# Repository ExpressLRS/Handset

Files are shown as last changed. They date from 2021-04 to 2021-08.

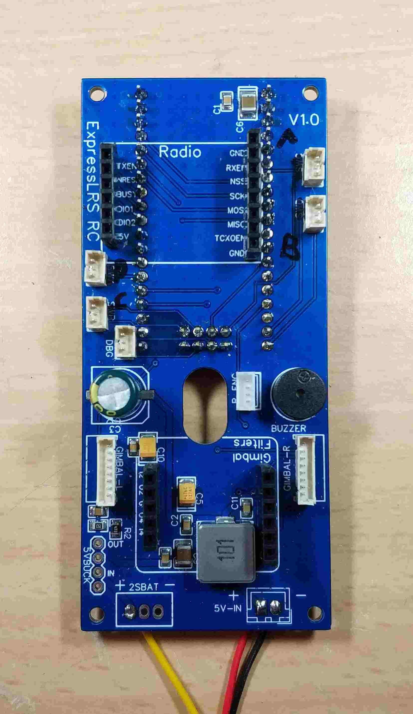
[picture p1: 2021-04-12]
Wiki/images/pcbs/main_component_side.jpg

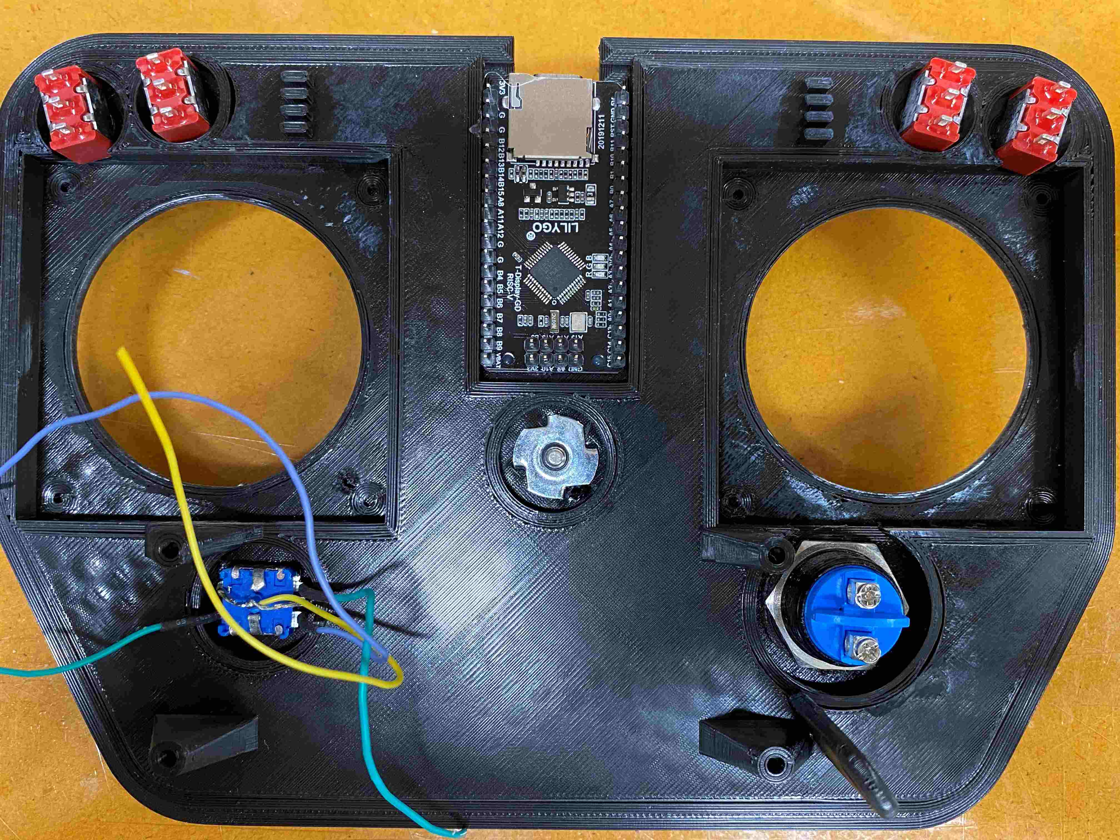
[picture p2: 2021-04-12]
Wiki/Main Board Assembly/20210327_000506065_iOS.jpg

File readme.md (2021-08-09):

The Express LRS Handset project is first and foremost an **experimental test bed** for pushing the envelope with what can be done with the ELRS radio link.  This handset will not replace your "daily driver", nor will it ever support radio protocols other than ELRS.  The Micro Controller Unit (MCU) does not run OpenTX.  The user interface is very rudimentary - simple text menus that are selected with a rotary encoder.  The firmware for this handset will never achieve "Release Candidate", let alone "Stable" status or be assigned a version number.  The software will be a continuous work in progress.

You will have to order and print parts, assemble, and solder this handset by hand as well as know how to build the firmware from source code and upload to the MCU.  

There will be pain.  There will be gnashing of teeth.  At this point is where we give you your first and final warning as passed down by ancient sailors:

***********************************************************
**Beyond this line there be Dragons . . . .**
***********************************************************

OK, now that we've set some expectations for this project we'll list some of the cool features of this handset and explain why you would want to go thru all of the effort to build instead of just purchasing a commercial handset.

1. Fly at the fastest and most consistent packet rate available.  Currently this is 500Hz, but this handset is capable of much faster.  Since the MCU doesn't have to deal with OpenTX, all of its CPU cycles are used to provide the most consistent ELRS signal to the receiver and thus your flight controller.  This is the main goal of this project, to increase the performance and stability of the ELRS radio link.  With this handset, you'll be right on the bleeding edge with the devs.
2. Uses FrSky M10 Hall Effect gimbals.  If you want the best radio signal, you start with the best data.
3. Hardware Filtering of gimbal data.  Select a level of hardware filtering by swapping out custom daughterboards to fine tune your feel.
4. Swappable RF deck.  RF deck is on a replaceable daughterboard so you can swap from 2.4GHz to 900MHz bands. (900 MHz modules currently not developed)  Can also swap to a lower powered RF module to save battery life if you don't need the higher power settings.
5. 1S2P 18650 LiPo battery.  Entire handset sips power from 2 LiPos in parallel.  Fly an entire weekend without charging.
6. Wireless Qi charging.  Build a charging cradle that will wirelessly charge your handset when you're not flying.
7. Internal Moxon antenna.  Transmit antenna is mounted internally for aesthetics, but can be mounted externally simply by drilling a hole.
8. Simplified operation.  Quad fliers rarely use 99% of the mixing functions of OpenTX since all of that is done in the Flight Controller.
9. Parts should be less than $100 U.S.
10. Did I mention wireless Qi charging?

At this time the best source of information on this project is our OneDrive folder:

https://1drv.ms/u/s!Ap0n6SxbLP9mspxu-dxmtthcFGTxvA?e=23NiK6

If you've read this far...



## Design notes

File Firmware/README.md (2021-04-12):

# Express_CX
Firmware for an experimental handset based on ExpressLRS

You're welcome to look around, but the project is still very much a work in progress and isn't particularly consumable yet. It's purpose is to test the limits of current RC technology and is likely only of interest to a very small subset of pilots.

This project builds on the awesome ExpressLRS high performance RC link https://github.com/AlessandroAU/ExpressLRS

The idea is to try and provide the highest quality RC data to the flight controller, building on the low latency, low jitter capabilities of ExpressLRS. The primary target is quadcopters running BetaFlight - this is not intended to be a general purpose RC controller.

The gimbal data is filtered before being sampled at high (currently 128kHz per channel) frequency and then run through the 1AUD filter designed by Chris Thompson https://github.com/ctzsnooze/1AUD-filter. This allows customisable filter settngs to be applied for different use cases. Latency is reduced through increased packet rate, currently up to 1kHz.

In future I hope to experiment with calculating the first and second order derivatives for each channel and sending those over the link along with the absolute stick positions.

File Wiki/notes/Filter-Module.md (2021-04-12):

filter top view

The filter module filters and buffers the signals from the gimbals before they are sampled by the ADC.

The project is on EasyEDA at https://easyeda.com/jbk1/expresscontroller

The circuit is from https://www.electronics-tutorials.ws/filter/second-order-filters.html

The cutoff frequency to use depends on both personal preference and how noisy the gimbals are. I'm currently using a cutoff of 339Hz which seems to work well, and plan to experiment with some higher frequency versions. The main purpose of having the filter on a module is to make it easy to test different cutoff frequencies.

339Hz can be achieved using 10k resistors and 47nF capacitors (or 15k with 33nF is similar at 322Hz). The footprints are for 0805 sized parts. For other cutoff frequencies there is a table of suggested values in the EasyEDA project description.

The pcb includes pads for changing Q using a resistor divider network in the feedback loop. I'm not currently using this, so the divider resistors on the back of the pcb can be left unpopulated. The ones on the front are still needed to complete the feedback circuit, but the value is not critical. I used 10k which would be a reasonable value if we wanted to modify Q later by adding the resistors on the back.

There are footprints for power supply decoupling capacitors on the back of the PCB, two 1210 and two 0805. The power rail is 5V so I'd recommend a 10V minimum rating on these capacitors. The larger ones can be anything in the 10 to 100 uF range, the smaller ones in the range 10 to 100 nF, ideally a mix of different values. The footprints don't have the polarity marked, so if using tantalum take extra care to get them the right way around! (but ceramics are cheaper and work fine here).

There is an assembly "cheat sheet" to help with where each component goes during assembly

build cheat sheet

Rear view of the filter
underside of filter

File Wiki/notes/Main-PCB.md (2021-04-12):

With all the interesting stuff on modules, the main PCB is mostly just filtering and plugs. The V1.0 PCB pictured has several mistakes on the silk screen - those will get fixed in future revisions.

Main pcb component side

Main pcb mcu side

The MCU used is a TTGO GD32V Risc-V board (http://www.lilygo.cn/prod_view.aspx?TypeId=50033&Id=1251). It comes with a good quality LCD and the GD32V processor has good ADC performance for sampling the gimbals at high frequency.

TODO - more info and build instructions

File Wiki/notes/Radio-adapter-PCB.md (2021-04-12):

Radio adapter top view

The radio module is mounted on an adapter pcb to make it easy to swap different versions. Different modules can be used via different adapters, but at the moment the E28 modules are recommended. They are available in 12, 20 and 27 dBm versions and any of these can be used with the same adapter.

The adapter is very straightforward to build, it has a simple 3v3 reg and filter capacitors on the back, and just the E28 on the front.

Don't forget to reposition the 0 ohm resistor on the E28 to use the UFL!

Radio adapter bottom view

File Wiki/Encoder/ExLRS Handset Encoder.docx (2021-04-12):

The encoder is the main input device for the handset. It is a 5-pin component. The side with 2 pins is the momentary switch, and the 3-pins are the encoder. The center pin on the encoder side is ground.

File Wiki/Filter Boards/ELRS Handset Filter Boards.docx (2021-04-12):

ELRS Handset Filter Boards

The ELRS handset uses a daughter board for hardware filtering of the gimbal signals. This is accomplished by routing the gimbal signals through a capacitor / resistor network before sending the signal to the MCU. There are many combinations of capacitor and resistor values that will result in various filtering solutions. Listed below are the 3 combinations we use to start.

Filtering Value | Capacitor | Resistor
322 Hz | 33nF | 15KΩ
530 Hz | 33nF | 9.1KΩ
946 Hz | 33nF | 5.1KΩ

Each filtering board uses 8 capacitors (C1-C8) and 12 resistors (All R’s on U1 side of board)

The filtering board must fit underneath the battery shield with some clearance to ensure there are no inadvertent shorts. When soldering the round pins, make sure the longer pins are the ones soldered into the board so the shorter pins will mate with the sockets in the main board. Also make sure you clip off the extra pins above the board, so it doesn’t contact the battery shield.

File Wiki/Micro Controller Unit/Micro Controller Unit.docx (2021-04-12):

Micro Controller Unit

The Micro Controller Unit (MCU) is the “brains” of the handset. It is installed in the front cover so that the LCD monitor faces out.

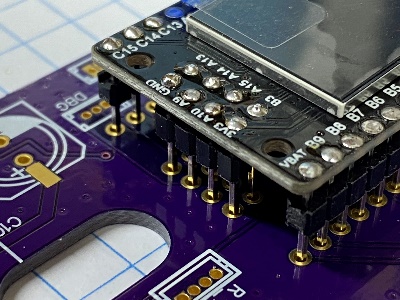
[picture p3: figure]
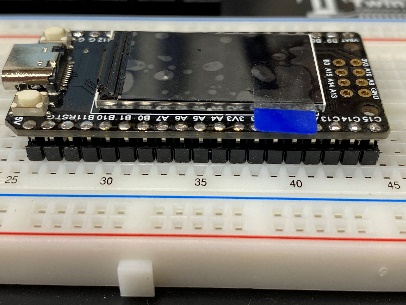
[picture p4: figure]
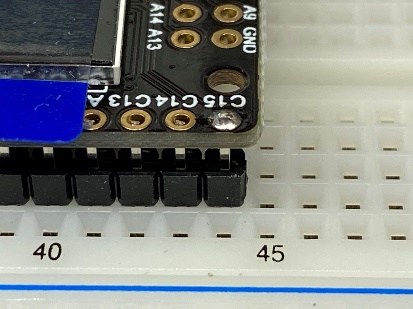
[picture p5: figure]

The MCU’s PCB need to sit as close as possible to the indentation in the case so that the LCD is readable after assembly. To accomplish this, you need to solder the header pins with as little sticking out the top as possible. The easiest way that we found was to utilize a solderless breadboard to hold the header pins until you get the MCU soldered in place.

Once the side header pins are soldered in place, use the Main PCB to locate and hold the 2 x 4 header pins in place for final soldering.

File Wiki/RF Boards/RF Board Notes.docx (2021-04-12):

RF Board Assembly Tips

When soldering the E28 board, smear flux paste onto the pads.

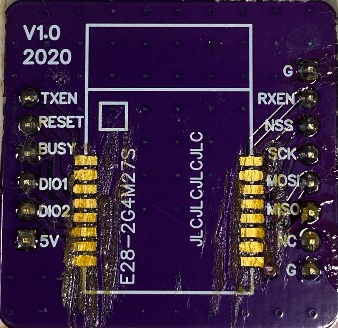
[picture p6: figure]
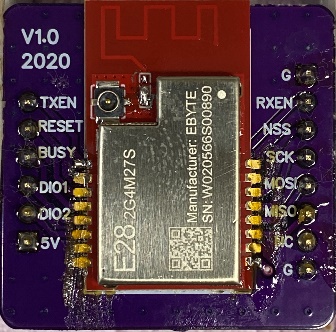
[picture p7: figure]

Place the E28 module on the board. The flux will help hold the module in place. Put a spot of solder paste on two opposite corners and tack the module in place.

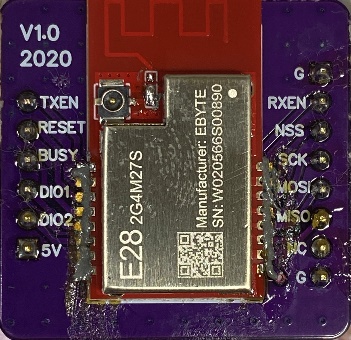
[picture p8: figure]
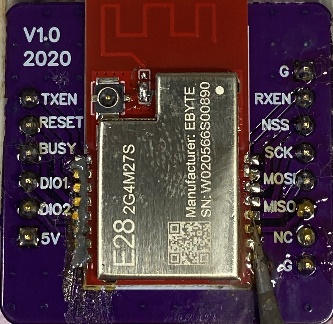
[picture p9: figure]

Put a bead of solder paste along the pads.

Drag solder ((42) HowTo: Drag Soldering Demo - YouTube (https://www.youtube.com/watch?v=wUyetZ5RtPs)) the module in place.

Visually inspect your work to ensure that there are no shorts between pads and that you have good, shiny connections at each point.

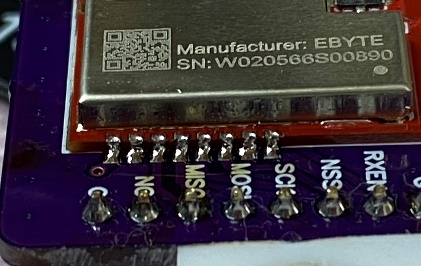
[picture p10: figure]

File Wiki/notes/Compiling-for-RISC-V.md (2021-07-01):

The current version of the handset uses the TTGO T-Display-GD32 RISC-V development board. Unfortunately since this is a relatively new architecture there are some rough edges in the support for it. This page documents the known issues and work-arounds.

1) Conflict with C++ bool in header file

Problem:

```
/home/testuser/.platformio/packages/framework-gd32vf103-sdk/GD32VF103_standard_peripheral/gd32vf103.h:179:41: error: redeclaration of C++ built-in type 'bool' [-fpermissive]
  179 | typedef enum {FALSE = 0, TRUE = !FALSE} bool;
      |                                         ^~~~
```

Cause:

The header file from the gd32 sdk isn't fully C++ compatible yet

Fix:

Comment out line 179 in .platformio/packages/framework-gd32vf103-sdk/GD32VF103_standard_peripheral/gd32vf103.h

```
// typedef enum {FALSE = 0, TRUE = !FALSE} bool;
```

see: https://github.com/riscv-mcu/GD32VF103_Firmware_Library/issues/1

2) Build fails with missing dfu-suffix tool

(Looks like this may have been fixed in recent platformio versions)

Problem:

```
Adding dfu suffix to firmware.bin
sh: 1: bin/dfu-suffix: not found
```

Cause:

dfu tools don't get automatically installed by platformio.

Fix:

Download dfu-utils from https://bintray.com/platformio/tool-packages (use search for tool-dfu to find the right package for your operating system). Extract the archive and copy it to (for linux)

$HOME/.platformio/packages/tool-dfuutil

see https://community.platformio.org/t/dfu-suffix-not-found-for-longan-nano-build/16710/4

3) dfu-util: Cannot open DFU device 28e9:0189

On Linux, indicates a need to add a rule to udev. Either create a new file in /etc/udev/rules.d or add to an existing one if you already have stuff for other dfu (e.g. betaflight FC controllers)

ACTION=="add", SUBSYSTEM=="usb", ATTRS{idVendor}=="28e9", ATTRS{idProduct}=="0189", MODE="0664", GROUP="whichever group you want to use for dfu access"
  
I just use my main userid group for access rather than going to the trouble of adding a special one for dfu.

You may need to run
```
udevadm control --reload-rules
udevadm trigger
```
as root after updating the rules for them to take effect.

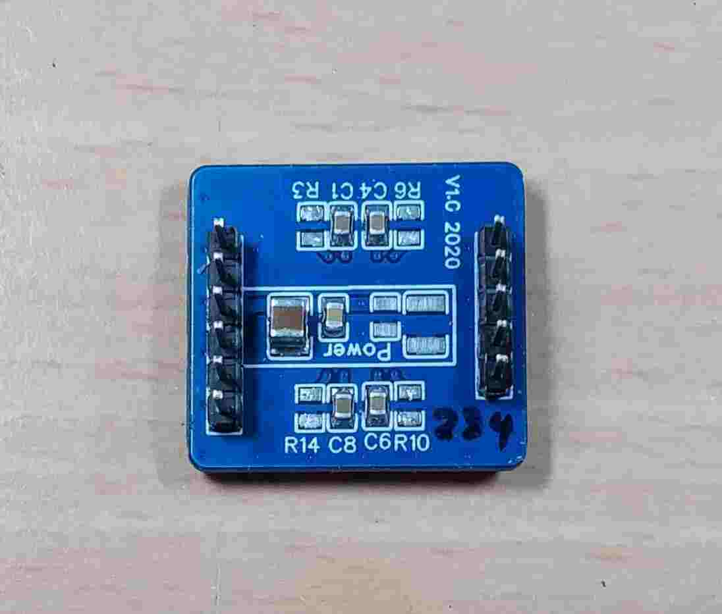
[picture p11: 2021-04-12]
Wiki/images/pcbs/filter_bottom.jpg

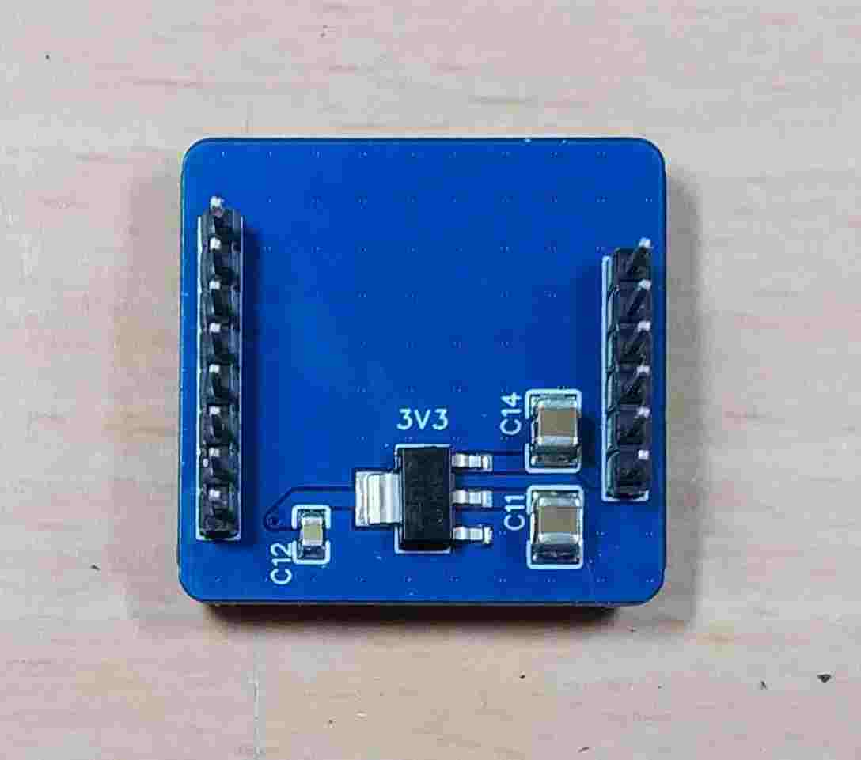
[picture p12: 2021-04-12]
Wiki/images/pcbs/rc_adapter_bottom.jpg

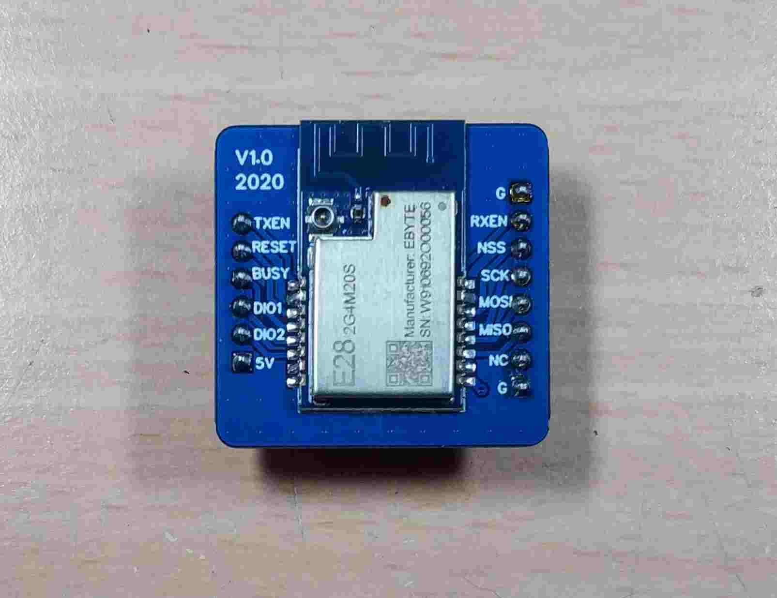
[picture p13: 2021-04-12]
Wiki/images/pcbs/rc_adapter_top.jpg

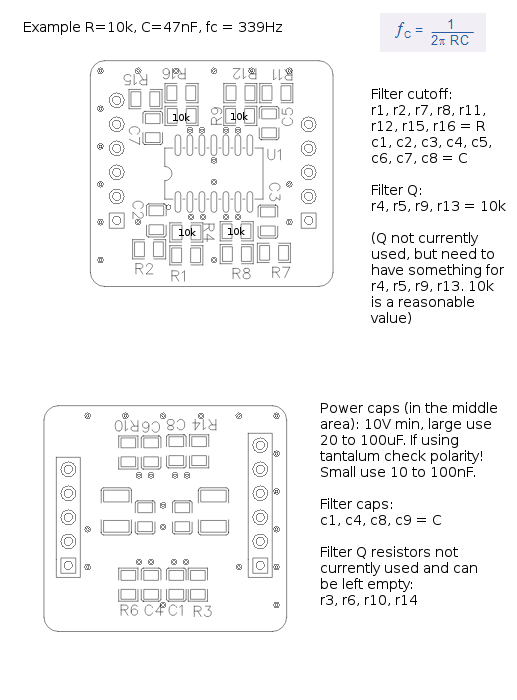
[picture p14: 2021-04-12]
Wiki/images/filter_cheat_sheet.png

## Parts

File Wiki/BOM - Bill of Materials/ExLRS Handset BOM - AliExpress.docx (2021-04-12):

# Stuff you’ll need to order from AliExpress

# (Quantities and specifics are in RED)

# E28-2G4M27S SX1280 Wireless module 2.4G 27dBm SPI Wireless ranging positioning LoRa Wireless Transceiver Long range 8000m

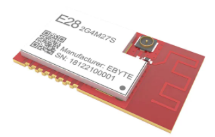
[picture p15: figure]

- E28 2G4M27S SX1280 Wireless module 2.4G 27dBm SPI Wireless ranging positioning LoRa Wireless Transceiver Long range 8000m|Fixed Wireless Terminals| - AliExpress (https://www.aliexpress.com/item/33004335921.html?spm=a2g0s.9042311.0.0.17854c4dX7L4KH)

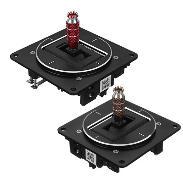
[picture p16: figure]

FrSky M10 Gimbals.

- Frsky m10 high sensitivity hall sensor gimbal for horus x10 x10s rc drone transmitter Sale - Banggood.com (https://usa.banggood.com/FrSky-M10-High-Sensitivity-Hall-Sensor-Gimbal-for-Horus-X10-X10S-RC-Drone-Transmitter-p-1277967.html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)
- FrSky M10 Gimbal For Horus X10 & X10s (horusrc.com) (https://www.horusrc.com/eng/frsky-m10-gimbal-for-horus-x10-x10s.html)

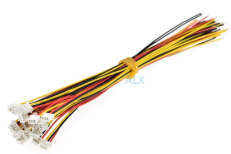
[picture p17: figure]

# 20PCS 150MM mini micro JST 1.25 3pin female plug connector with wire 1.25MM 3pin 3p cable (Order 3 and 4 pin connectors)

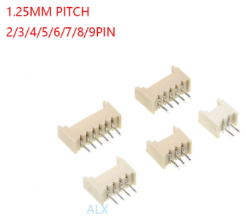
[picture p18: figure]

- 20PCS 150MM mini micro JST 1.25 3pin female plug connector with wire 1.25MM 3pin 3p cable|Connectors| - AliExpress (https://www.aliexpress.com/item/32886112821.html?spm=a2g0s.9042311.0.0.17854c4dX7L4KH)

# 20pcs MICRO JST connector 1.25MM PITCH MALE pin header 3P/4P/8P Straight needle FOR PCB BOARD 1.25 (Order 3,4, and 8P connectors)

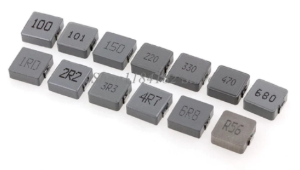
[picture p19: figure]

- 20pcs MICRO JST connector 1.25MM PITCH MALE pin header 2P/3P/4P/5P/6P/7P/8P/9P/10P/11P/12P Straight needle FOR PCB BOARD 1.25|Connectors| - AliExpress (https://www.aliexpress.com/item/32887462907.html?spm=a2g0s.9042311.0.0.17854c4dX7L4KH)

# Integrally Molded 10*10*4 Power Inductor 1040 100UH (Order 100UH Inductors)

- Integrally Molded 10*10*4 Power Inductor 1040 0.56UH 1UH 2.2UH 3.3UH 4.7UH 6.8UH 10UH 100UH 115UH 22UH 33UH 47UH 68UH 10X10X4|Inductors| - AliExpress (https://www.aliexpress.com/item/4000623206812.html?spm=a2g0s.9042311.0.0.17854c4dX7L4KH)

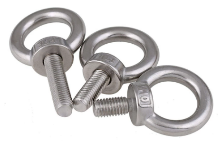
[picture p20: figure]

# M4 Lifting Eye Bolts 304 stainless steel Lifting Ring Screws Eye Bolt (Order M4 Eye Bolts)

- M3 M4 M5 M6 M8 M10 M12 Lifting Eye Bolts 304 stainless steel Lifting Ring Screws Eye Bolt|Bolts| - AliExpress (https://www.aliexpress.com/item/33010957846.html?spm=a2g0s.9042311.0.0.27424c4dr6YM29)

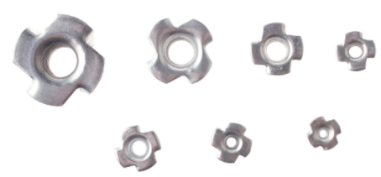
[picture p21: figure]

# 5/10/20/50PCS M3 M4 M5 M6 M8 M10 M12 Zinc Plated Four Claws Nut Speaker T-nut Blind Pronged Insert Tee Nut Furniture Hardware (Order 5 pieces M4 T-Nut)

- 5/10/20/50PCS M3 M4 M5 M6 M8 M10 M12 Zinc Plated Four Claws Nut Speaker T nut Blind Pronged Insert Tee Nut Furniture Hardware|Nuts| - AliExpress (https://www.aliexpress.com/item/33041388035.html)

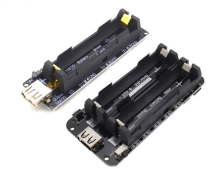
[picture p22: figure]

# ESP32 ESP32S For Wemos For Raspberry Pi 18650 Battery Charge Shield Board V3 Micro USB Port Type-A USB 0.5A (Order the 2-cell shield, no charger)

- ESP32 ESP32S For Wemos For Raspberry Pi 18650 Battery Charge Shield Board V3 Micro USB Port Type A USB 0.5A|Integrated Circuits| - AliExpress (https://www.aliexpress.com/item/4001282850260.html?spm=a2g0s.9042311.0.0.27424c4dr6YM29)


# 10pcs Plum handle 15mm rotary encoder coding switch / EC11 / digital potentiometer with switch 5 Pin

- 10pcs Plum handle 15mm rotary encoder coding switch / EC11 / digital potentiometer with switch 5 Pin|Potentiometers| - AliExpress (https://www.aliexpress.com/item/32879562482.html?spm=a2g0s.9042311.0.0.27424c4dr6YM29)


# Flysky / Frsky Taranis QX7 X7S X9D Plus Transmitter Parts Tighten Switch Spacer Tool

- Flysky / Frsky Taranis QX7 X7S X9D Plus Transmitter Parts Tighten Switch Spacer Tool|Parts & Accessories| - AliExpress (https://www.aliexpress.com/item/32995614382.html?spm=a2g0s.9042311.0.0.27424c4dr6YM29)


# Switch For RadioLink AT9S Futaba JR Frsky X9D Plus QX7 FlySky Walkera WFLY RadioLink switch parts (Be sure to select your desired switches, washers, and nuts)

- Switch For RadioLink AT9S Futaba JR Frsky X9D Plus QX7 FlySky Walkera WFLY RadioLink switch parts|Parts & Accessories| - AliExpress (https://www.aliexpress.com/item/33017227469.html?spm=a2g0s.9042311.0.0.27424c4dr6YM29)


# U.FL IPX IPEX UFL to RP-SMA SMA Female Male Antenna WiFi Pigtail 1.13 Cable ufl 1.13mm Pick Your Length (Order SMA Female 90, 15cm length)

# - U.FL IPX IPEX UFL to RP SMA SMA Female Male Antenna WiFi Pigtail 1.13 Cable ufl 1.13mm Pick Your Length|Connectors| - AliExpress (https://www.aliexpress.com/item/4000166668788.html?spm=a2g0s.9042311.0.0.27424c4dr6YM29)


# LILYGO® TTGO T-Display-GD32 GD32VF103CBT6 Main Chip ST7789 1.14 Inch IPS 240x135 Resolution Minimalist Development Board


- LILYGO® TTGO T Display GD32 GD32VF103CBT6 Main Chip ST7789 1.14 Inch IPS 240x135 Resolution Minimalist Development Board|Circuits| - AliExpress (https://www.aliexpress.com/item/4000598356310.html?spm=a2g0s.9042311.0.0.27424c4dr6YM29)

# 100PCS LM324DR LM324 SOP-14 3.9MM (Only need 3, but 100 qty. is smallest I could find)

- 100PCS LM324DR LM324 SOP 14 3.9MM|amplifier home|amplifier 3gamplifier bluetooth - AliExpress (https://www.aliexpress.com/item/849324878.html?spm=a2g0s.9042311.0.0.27424c4dr6YM29)


# 1pcs Wireless Charging Board 10W Fast Qi Standard Charging Universal DIY 3-Coils PCB (Order both transmitter and receiver)

- 1pcs Wireless Charging Board 10W Fast Qi Standard Charging Universal DIY 3 Coils PCB|Integrated Circuits| - AliExpress (https://www.aliexpress.com/item/32980118867.html?spm=a2g0s.9042311.0.0.27424c4dsHPZHS)

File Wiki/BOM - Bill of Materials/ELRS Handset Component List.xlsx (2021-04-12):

ELRS PCB Component Callouts
Main PCB
C1, C2,C4, C8, C11 | 1uF
C3, C12 | 470uF | Only need one or the other, there are footprints for an SMD or through hole capacitor in this space
C5, C6, C10 | 100uF | Tantalum Cap. Check polarity when installing.
C7 | 0.1uF
C9 | 22uF
C13 | Not used
C14 | 10uF
R1 | 16K
R2 | 47.5K
Power Inductor | 100uH
Buzzer |  | Needs to be the type that beeps when you feed it power, like used on quads. 5mm between pins
Gimbal-R/L | 8-pin socket
SWA/B/C/D/DBG | 3-pin socket
R ENC | 4-pin socket | Alternative: 3-pin socket using the 3 holes closest to the bottom of board. Top hole is ground.
Filter Board
R1, R2, R4, R5, R7, R8, | 5.1K or 9.1K or 15K | <<-- This value selects the filter board speed 946Hz/530Hz/322Hz
R9, R11, R12, R16, R15, R17 |  | <<-- This value selects the filter board speed 946Hz/530Hz/322Hz
C1, C2, C3, C4, C5, C6, C7, C8 | 33nF
Power Large capacitor | 10 to 100 uF | Only need to populate one large and one small power capacitor position.
Power Small capacitor | 0.01 to 0.1 uF | Only need to populate one large and one small power capacitor position.
R3, R6, R10, R14 | Unpopulated
RF Board
RF Module | E28 Ebyte RF Module | 3 models available with 12, 20 and 27dBm output.
 |  | 12dBm is ok for small indoors, 20dBm is a good tradeoff between range and battery life,
 |  | and 27dBm is your max range option
3V3 | 3.3V Regulator
C11, C14 | 10 to 100 uF
C12 | 0.1 uF

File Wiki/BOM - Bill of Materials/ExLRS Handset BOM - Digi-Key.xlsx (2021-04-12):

Manufacturer Part Number | Manufacturer | Digi-Key Part Number | Customer Reference | Reference Designator | Packaging | Part Status | Quantity | Unit Price | Extended Price | Quantity Available | Mfg Std Lead Time | Description | RoHS Status | Lead Free Status | REACH Status
CL21B105KOFNNNG | Samsung Electro-Mechanics | 1276-6471-1-ND | ExLRS Tx Handset | C1, C2,C4, C8, C11 | Cut Tape (CT) | Active | 5 | 0.1 | $0.50 | 264049 | 28 Weeks | CAP CER 1UF 16V X7R 0805 | ROHS3 Compliant | Lead free | REACH Unaffected
CL21B104KACNNNC | Samsung Electro-Mechanics | 1276-1099-1-ND | ExLRS Tx Handset | C7 | Cut Tape (CT) | Active | 1 | 0.1 | $0.10 | 32023 | 28 Weeks | CAP CER 0.1UF 25V X7R 0805 | ROHS3 Compliant | Lead free | REACH Unaffected
CL21A226MOCLRNC | Samsung Electro-Mechanics | 1276-6780-1-ND | ExLRS Tx Handset | C9 | Cut Tape (CT) | Active | 1 | 0.36 | $0.36 | 902296 | 28 Weeks | CAP CER 22UF 16V X5R 0805 | ROHS3 Compliant | Lead free | REACH Unaffected
RMCF0805FT47K5 | Stackpole Electronics Inc | RMCF0805FT47K5CT-ND | ExLRS Tx Handset | R2 | Cut Tape (CT) | Active | 1 | 0.1 | $0.10 | 139544 | 21 Weeks | RES 47.5K OHM 1% 1/8W 0805 | ROHS3 Compliant | Lead free | REACH Unaffected
RC0805FR-0716KL | Yageo | 311-16.0KCRCT-ND | ExLRS Tx Handset | R1 | Cut Tape (CT) | Active | 1 | 0.1 | $0.10 | 497289 | 20 Weeks | RES SMD 16K OHM 1% 1/8W 0805 | ROHS3 Compliant | Lead free | REACH Unaffected
16ZLJ470MTA8X11.5 | Rubycon | 1189-1549-1-ND | ExLRS Tx Handset | C3, C12 | Cut Tape (CT) | Active | 2 | 0.53 | $1.06 | 37385 | 20 Weeks | CAP ALUM 470UF 20% 16V RADIAL | ROHS3 Compliant | Lead free | REACH Unaffected
C0805C333K1RECAUTO | KEMET | 399-C0805C333K1RECAUTOCT-ND | ExLRS Tx Handset |  | Cut Tape (CT) | Active | 1 | 0.27 | $0.27 | 4271 | 27 Weeks | CAP CER 0805 33NF 100V X7R 10% | ROHS3 Compliant | Lead free | REACH Unaffected
RC0805FR-075K1L | Yageo | 311-5.10KCRCT-ND | ExLRS Tx Handset |  | Cut Tape (CT) | Active | 1 | 0.1 | $0.10 | 1475887 | 20 Weeks | RES SMD 5.1K OHM 1% 1/8W 0805 | ROHS3 Compliant | Lead free | REACH Unaffected
RC0805FR-0710KL | Yageo | 311-10.0KCRCT-ND | ExLRS Tx Handset |  | Cut Tape (CT) | Active | 1 | 0.1 | $0.10 | 11495312 | 20 Weeks | RES SMD 10K OHM 1% 1/8W 0805 | ROHS3 Compliant | Lead free | REACH Unaffected
RC0805FR-0720KL | Yageo | 311-20.0KCRCT-ND | ExLRS Tx Handset |  | Cut Tape (CT) | Active | 1 | 0.1 | $0.10 | 1049813 | 20 Weeks | RES SMD 20K OHM 1% 1/8W 0805 | ROHS3 Compliant | Lead free | REACH Unaffected
CL32F106ZOHNNNE | Samsung Electro-Mechanics | 1276-2865-1-ND | ExLRS Tx Handset | C11, C14 | Cut Tape (CT) | Active | 1 | 0.32 | $0.32 | 2360 | 28 Weeks | CAP CER 10UF 16V Y5V 1210 | ROHS3 Compliant | Lead free | REACH Unaffected
CL32A226MOJNNNE | Samsung Electro-Mechanics | 1276-1851-1-ND | ExLRS Tx Handset |  | Cut Tape (CT) | Active | 1 | 0.39 | $0.39 | 22823 | 28 Weeks | CAP CER 22UF 16V X5R 1210 | ROHS3 Compliant | Lead free | REACH Unaffected
CL21B104KACNNNC | Samsung Electro-Mechanics | 1276-1099-1-ND | ExLRS Tx Handset | C12 | Cut Tape (CT) | Active | 1 | 0.1 | $0.10 | 32023 | 28 Weeks | CAP CER 0.1UF 25V X7R 0805 | ROHS3 Compliant | Lead free | REACH Unaffected
GRM2195C1H113JA01D | Murata Electronics | 490-8297-1-ND | ExLRS Tx Handset |  | Cut Tape (CT) | Active | 1 | 0.44 | $0.44 | 20 | 23 Weeks | CAP CER 0.011UF 50V C0G/NP0 0805 | ROHS3 Compliant | Lead free | Not Available
293D107X06R3B2TE3 | Vishay Sprague | 718-293D107X06R3B2TE3CT-ND | ExLRS Tx Handset |  | Cut Tape (CT) | Active | 1 | 0.6 | $0.60 | 3029 | 44 Weeks | CAP TANT 100UF 20% 6.3V 1411 | ROHS3 Compliant | Lead free | Not Available
PPTC061LFBN-RC | Sullins Connector Solutions | S7004-ND | ExLRS Tx Handset |  | Tray | Active | 10 | 0.483 | $4.83 | 64319 | 5 Weeks | CONN HDR 6POS 0.1 TIN PCB | ROHS3 Compliant | Lead free | REACH Unaffected
PPTC081LFBN-RC | Sullins Connector Solutions | S7006-ND | ExLRS Tx Handset |  | Tray | Active | 10 | 0.608 | $6.08 | 194620 | 5 Weeks | CONN HDR 8POS 0.1 TIN PCB | ROHS3 Compliant | Lead free | REACH Unaffected
PPTC051LFBN-RC | Sullins Connector Solutions | S6103-ND | ExLRS Tx Handset |  | Tray | Active | 1 | 0.47 | $0.47 | 22819 | 5 Weeks | CONN HDR 5POS 0.1 TIN PCB | ROHS3 Compliant | Lead free | REACH Unaffected
CMI-9605-0580T | CUI Devices | 102-CMI-9605-0580T-ND | ExLRS Tx Handset |  | Box | Active | 10 | 1.11 | $11.10 | 348 | 11 Weeks | BUZZER, 9.6 MM X 5 MM DEEP, M, 5 | ROHS3 Compliant | Lead free | Not Available
CL21B473KBCNNNC | Samsung Electro-Mechanics | 1276-1250-1-ND | ExLRS Tx Handset |  | Cut Tape (CT) | Active | 1 | 0.1 | $0.10 | 3929 | 28 Weeks | CAP CER 0.047UF 50V X7R 0805 | ROHS3 Compliant | Lead free | REACH Unaffected
RC0805FR-079K1L | Yageo | 311-9.10KCRCT-ND | ExLRS Tx Handset |  | Cut Tape (CT) | Active | 1 | 0.1 | $0.10 | 44142 | 20 Weeks | RES SMD 9.1K OHM 1% 1/8W 0805 | ROHS3 Compliant | Lead free | REACH Unaffected
RC0805FR-0715KL | Yageo | 311-15.0KCRCT-ND | ExLRS Tx Handset |  | Cut Tape (CT) | Active | 1 | 0.1 | $0.10 | 554381 | 20 Weeks | RES SMD 15K OHM 1% 1/8W 0805 | ROHS3 Compliant | Lead free | REACH Unaffected
SMC-1-12-1-GT | Adam Tech | 2057-SMC-1-12-1-GT-ND |  |  | Bulk | Active | 1 | 0.78 | $0.78 | 155 | 9 Weeks | MACHINE PIN SOCKET 12P 2.54MM PI | ROHS3 Compliant | Lead free | REACH Unaffected
D01-9922046 | Harwin Inc. | 952-1900-ND |  |  | Tube | Active | 2 | 4.03 | $8.06 | 668 | 8 Weeks | CONN SIL HDR MALE PIN 20POS TIN | ROHS3 Compliant | Lead free | REACH Unaffected

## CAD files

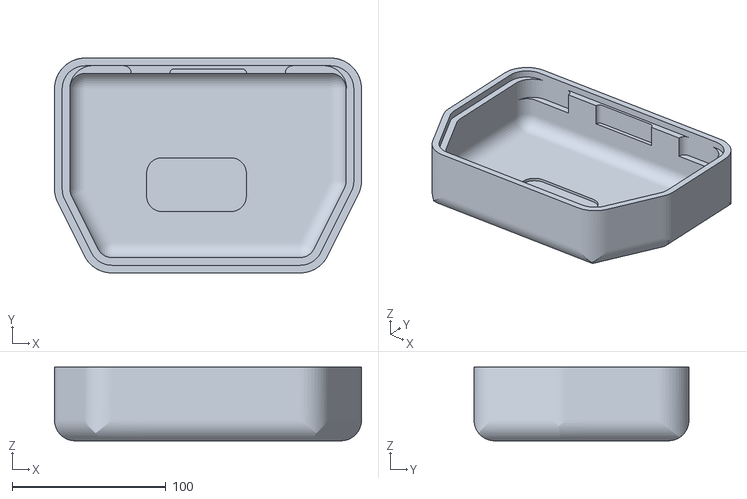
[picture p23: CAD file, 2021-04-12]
ELRS Transmitter Case .STLs/ELRS Handset Bottom.stl
200.0 x 140.0 x 48.0

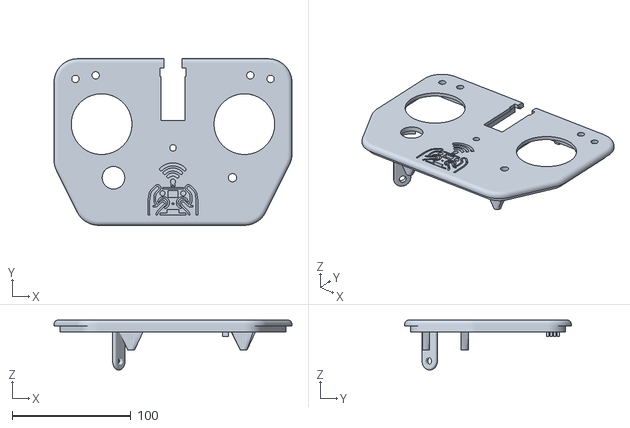
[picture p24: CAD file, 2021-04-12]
ELRS Transmitter Case .STLs/ELRS Handset Top (No Initials).stl
200.0 x 140.0 x 42.0

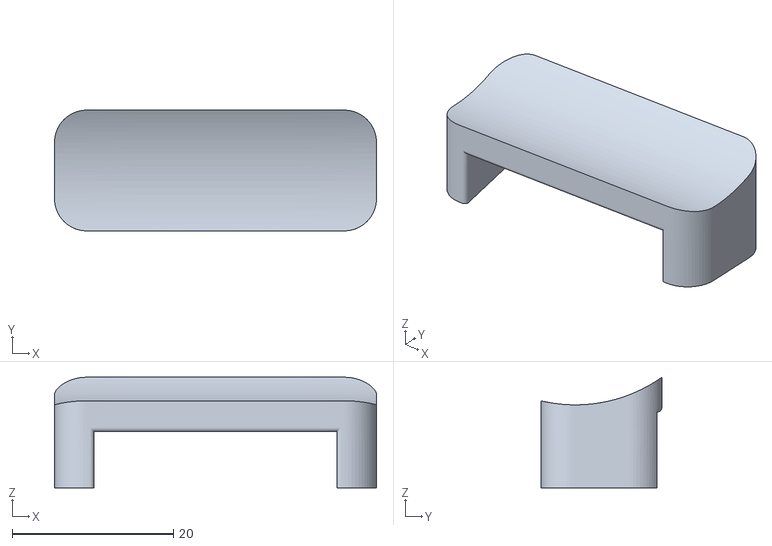
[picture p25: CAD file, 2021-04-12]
ELRS Transmitter Case .STLs/Front Foot (3D Print).stl
40.0 x 15.0 x 13.7

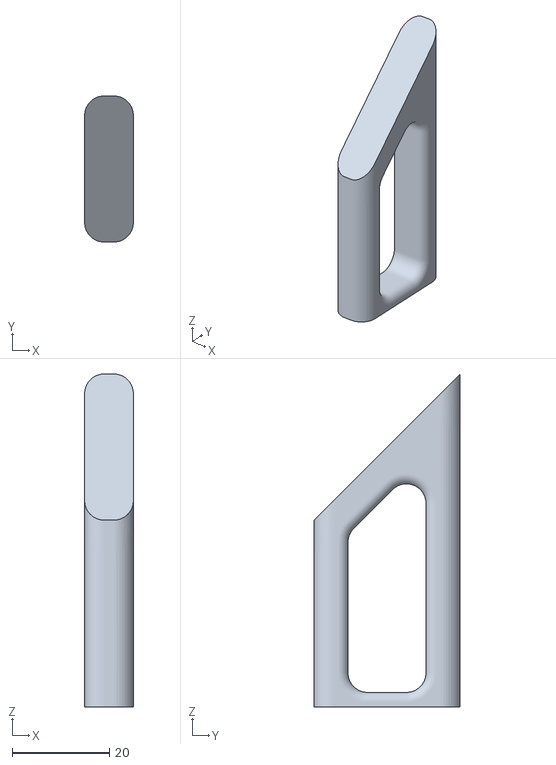
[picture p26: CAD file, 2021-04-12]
ELRS Transmitter Case .STLs/Rear Foot (3D Print).stl
10.0 x 30.0 x 68.4

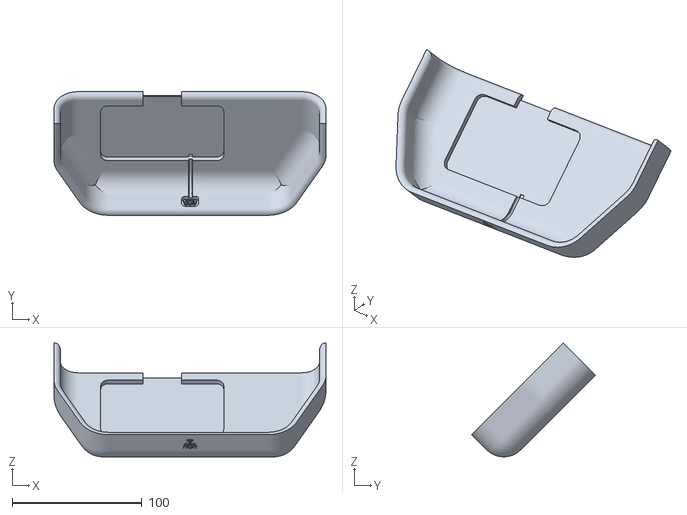
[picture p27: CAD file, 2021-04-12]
ELRS Transmitter Case .STLs/Cradle (3D Print).stl
210.0 x 95.5 x 87.8

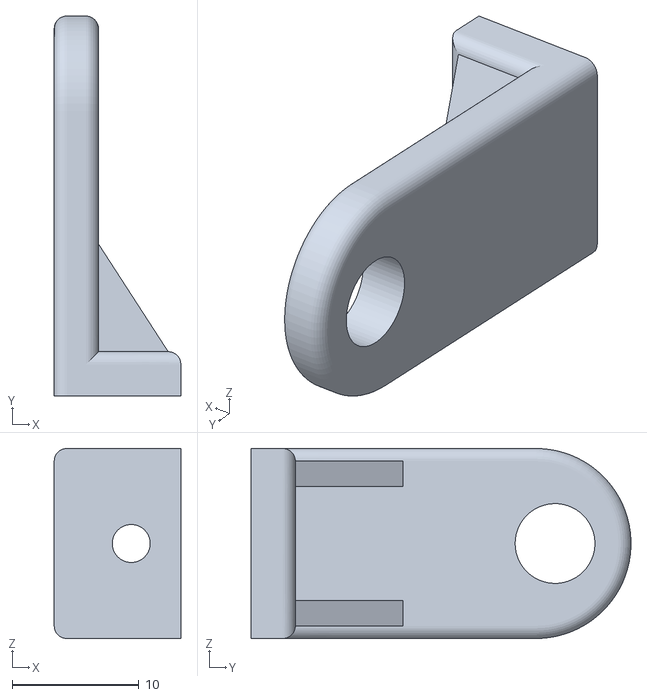
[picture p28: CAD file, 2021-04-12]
ELRS Transmitter Case .STLs/Internal Antenna Mount.stl
10.0 x 30.0 x 15.0

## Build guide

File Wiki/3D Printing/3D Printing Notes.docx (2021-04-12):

3D Printing Instructions

- Use filament with a high temperature tolerance if possible, like ABS. The case will spend time in the hot trunk of your car and some of the components will get warm during use or charging. With that being said, my prototypes were all printed from PLA and they survived.
- Set your slicer “Horizontal Layer” thickness to at least 1 – 1.5mm, especially when printing the front cover. There are several components like the 4mm T-nut and the screws that will need some material to bite into to hold.
- If you need to make a hole for screws, use a hot soldering iron.

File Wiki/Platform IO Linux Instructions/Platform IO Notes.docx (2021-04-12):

Notes for Platform I/O on Linux

To use the UBS-C port on the RISC-V MCU, Platform IO needs to have dfu-util installed.

Index of /releases (sourceforge.net) (http://dfu-util.sourceforge.net/releases/)

Change platformio.ini, comment/uncomment your upload method:

upload_protocol = dfu

; upload_protocol = serial

; upload_port = /dev/ttyUSB1

Linux users have to install udev (https://en.wikipedia.org/wiki/Udev) rules for PlatformIO supported boards/devices. The latest version of rules may be found at https://raw.githubusercontent.com/platformio/platformio-core/master/scripts/99-platformio-udev.rules

Frequently Asked Questions — PlatformIO 5.2.0a4 documentation (https://docs.platformio.org/en/latest/faq.html)

Comment out the following line in file:

-See “Using Platform I/O with RISC-V" in the notes folder.

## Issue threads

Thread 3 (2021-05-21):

How to bind the receiver

norulers, 2021-05-21:
HI，
I made a handset, how to work with my (targets=DIY_2400_RX_ESP8285_SX1280_via_UART) receiver connection ？
Edit  platformio.ini   -D MY_UID=0x17,0x13,0x31,0x19,0x23,0xEB   ?

JBKingdon, 2021-05-21:
Yes, the UID from normal elrs is printed near the start of the build, so copy those values into your handset Ini to match.

JBKingdon, 2021-05-21:
Jump in the elrs discord #handset if you have questions 😃

JBKingdon, 2021-05-21:
The handset firmware has to match a particular release of the Rx firmware. The handset code in the master branch has a define to set the level, currently tested against elrs v1 rc3

norulers, 2021-05-25:
``Verbose mode can be enabled via `-v, --verbose` option
UID bytes: 10,183,12,124,56,3
Installing GitPythonRequirement already satisfied: GitPython in c:\users\norulers\.platformio\penv\lib\site-packages (3.1.17)

JBKingdon, 2021-06-27:
Hey @norulers - sorry I must have missed your last update. Did you get things working?

JBKingdon, 2021-07-28:
Hi @norulers , how are things going? Do we still need this issue or shall I close it now?

norulers, 2021-07-29:
After updating the firmware, it can be used normally.

Closed 2021-07-29.

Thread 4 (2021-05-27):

Switches not working correctly with elrs V1 RC2+

JBKingdon, 2021-05-27:
The switches aren't updating correctly. If aux2 is moved, changes to aux3 and aux4 are ignored until aux2 is moved back to it's original position. Similarly aux3 blocks aux4.

Closed 2021-05-27.

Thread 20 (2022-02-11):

the one drive link isn't working...

JonnyPhenomenon, 2022-02-11:
dead link to onedrive on the handset readme.md

JBKingdon, 2022-02-12:
Ah, that's a shame. FireNWater put that together when he was doing his build.

FireNWater, 2022-02-12:
Ahhh, the link must have timed out. I’ll see if I can send it to James again.

daygp, 2022-04-07:
Seems that the onedrive link on the handset readme.md is down again

JBKingdon, 2022-04-09:
Ah, sorry about that. We'll have to see if we can move the information over to the wiki where it's easier to get at. I should probably also mention that this project is a bit out of date at the moment - I still haven't done the updates for compatibility with elrs v2

Ultraexpert, 2022-10-03:
Will this work with v.3? It would be fun to build this tx?

JBKingdon, 2022-10-03:
> Will this work with v.3? It would be fun to build this tx?

I'm afraid the current software doesn't support elrs V3 or even V2. It would be possible to bring it up to date, but it's a fair bit of work and I can't give any estimate of if/when it will get done.

meistertek, 2024-04-29:
> I'm afraid the current software doesn't support elrs V3 or even V2. It would be possible to bring it up to date, but it's a fair bit of work and I can't give any estimate of if/when it will get done.

What would be involved to update this project to V3 Express LRS. I have some experience designing and fabricating boards using KiCad. I have also fabricated and programmed these boards using small cnc mill. I also have programmed these boards using the processing and MicroPython programming languages. Would these skill sets be enough to update and resurrect the ELRS Handset project?

JBKingdon, 2024-04-29:
Responded in https://github.com/ExpressLRS/Handset/issues/23

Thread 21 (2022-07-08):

hardware filtering

armor66, 2022-07-08:
Just for the record and guess issue should be closed. My hardware filtering board with uPC324G didn't work properly. So I took rail-to-rail MC33204 and there are no troubles with low input.

JBKingdon, 2022-07-25:
Hi, thanks for the update, that's useful to know.

Closed 2022-07-25.

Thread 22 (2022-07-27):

Telemetry support

armor66, 2022-07-27:
Hi, can you please make it clear if it possible to get the rest telemetry data from FC. Why "TLMheader" is always 0x01? I guess that would be 0x14 for link statistics and 0x02, 0x08, 0x21 for gps, battery and flight mode respectively. Is it ELRS version limitation?

JBKingdon, 2022-08-03:
Hi, I haven't used the extended telemetry from the FC so never implemented support in the handset code. There's quite a lot of complexity you'd need to add to do that, but it should be possible to port it across from mainline elrs if you are motivated.

armor66, 2022-08-03:
Ok. I just saw the comment: "if (TLMheader == 1) // they changed the header value for new telem support" (It confused me, who are "they"). Does this have to do with SX1280 files? I'll try, but C++ isn't my thing.

JBKingdon, 2022-08-04:
That's for dealing with the "basic" telemetry that comes from the receiver itself, things like RSSI, SNR and LQ. "They" in this case means the rest of the devs on the main elrs project. They changed the constant for the packets so I had to update the handset code to match for compatibility mode. For the most part I don't run mainline elrs, I have my own fork to experiment with. I added compatibility mode for a friend so that he could use standard elrs on his receivers (since my fork also requires a custom version of betaflight...)

armor66, 2022-08-04:
Ok, could dig in

Closed 2022-08-04.

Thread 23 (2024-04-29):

Resurrect Project

meistertek, 2024-04-29:
@JBKingdon
> I'm afraid the current software doesn't support elrs V3 or even V2. It would be possible to bring it up to date, but it's a fair bit of work and I can't give any estimate of if/when it will get done.

What would be involved to update this project to V3 Express LRS? I have some experience designing and fabricating boards using KiCad. I have also fabricated and programmed these boards using small cnc mill. I also have programmed these boards using the processing and MicroPython programming languages. Would these skill sets be enough to update and resurrect the ELRS Handset project?

JBKingdon, 2024-04-29:
Hi @meistertek
The main work to be done is to add support for the over-the-air format in V3 and then lots of testing. So the primary skill set needed initially is C/C++.

meistertek, 2024-04-30:
Thanks @JBKingdon , I'll work on building a handset and while doing that I'll take a look at the existing C/C++ code. I'll then look at the V3 over-the-air format code to see if I'd be able to figure out how to add it to the existing handset. And then be ready for lots of testing!

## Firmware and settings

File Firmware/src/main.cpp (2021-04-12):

#include <stdio.h>
#include <string.h>
#include "config.h"
#include "utils.h"
#include "SX1280.h"
#include "SX1280_hal.h" //  only needed for MAX_PRE_PA_POWER
#include "FHSS.h"
#include "SimpleStore.h"

// Next:
//    UI improvements
//    Stick calibration
//    Auto power limit when disarmed - or full dynamic power?

//    msp for vtx channel?
   // Info from BF msp.c:
   // uint16_t newFrequency = sbufReadU16(src);
   // if (newFrequency <= VTXCOMMON_MSP_BANDCHAN_CHKVAL) {  // Value is band and channel
   //     const uint8_t newBand = (newFrequency / 8) + 1;
   //     const uint8_t newChannel = (newFrequency % 8) + 1;
//

// Prevents some debug print statements when uncommented
// #define DEBUG_SUPPRESS

// Uncomment to enable some debug output on the LCD
// #define DEBUG_STATUS

// uncomment for setting up the gimbals
#define STICK_CALIBRATION


extern "C" {

#include "gd32vf103.h"
#include "systick.h"

#ifdef LONGAN_NANO
#include "lcd/lcd.h"
#elif defined(T_DISPLAY) || defined(PCB_V1_0)
#include "lcd-tdisplay/lcd.h"
#else
#error "Define the board type before compiling"
#endif

} // extern "C"

// find a better place for these
#define RC_DATA_PACKET  0b00
#define MSP_DATA_PACKET 0b01
#define SYNC_PACKET     0b10
#define TLM_PACKET      0b11

#define CRSF_FRAMETYPE_LINK_STATISTICS 0x14

#define LCD_PWM_MAX     124
#define LCD_PWM_CHARGING  5
#define LCD_PWM_ARMED    20

enum SWITCH_POSITIONS
{
   SWITCH_LOW,
   SWITCH_MID,
   SWITCH_HIGH
};

// params
enum EDITABLE_PARAMS {
   PARAM_NONE,    // must be first
   PARAM_POWER,
   PARAM_RATE,
   PARAM_TLM_INT,
   PARAM_FILTER_MODE,
   PARAM_SYNC_WHEN_ARMED,
   PARAM_N_PARAMS // must be last
};

uint8_t paramToChange = PARAM_NONE;

bool syncWhenArmed = true; // need this on for testing with no switches attached

// current and sent switch values, used for prioritising sequential switch transmission
uint8_t currentSwitches[MAX_SWITCHES] = {SWITCH_LOW};
uint8_t sentSwitches[MAX_SWITCHES] = {SWITCH_LOW};

uint8_t nextSwitchIndex = 0; // for round-robin sequential switches


// Methods that need to be callable from the C interrupt handlers
extern "C" {
   void SendRCdataToRF();
   void HandleTLM();
   void HandleFHSS();
   void ProcessTLMpacket();
}

// debug baud rate
#define BAUDRATE (460800U)

// low battery warning threshold in tenths of a volt
#define LOW_BAT_THRESHOLD (34)

bool batteryLow = false;

unsigned long interval, adcInterval;
unsigned int nSamples=0;
char debugStr[64];
bool debugReady = false;

// static bool led=0;
unsigned long lastButtonTime = 0;
bool buttonMoved = false;
bool doTX = false;

// storage for DMA ouput from ADC
#define DMA_BUFFER_LEN (4)          // maybe double buffer?
uint16_t adc_value[DMA_BUFFER_LEN];

// Storage format for persistent params
struct persistentData_s {
   int8_t txPower;      // signed so that we don't have to add an offset when saving
   uint8_t airmodeIndex;
   uint8_t telemRatio;
   uint8_t sync;
   uint8_t filterMode;
};

typedef persistentData_s persistentData_t;

#define CONFIG_STORE_ID 1


// filters

#include "1AUDfilterInt.h"

struct filterSpec_s {
   uint16_t minCutoff;
   uint16_t maxCutoff;
   float beta;
};

filterSpec_s raceFilter =      {200, 500, 0.01f};
filterSpec_s freestyleFilter = {100, 250, 0.01f};
filterSpec_s cinematicFilter = {10,   50, 0.01f};

enum FILTER_MODE {
   FILTER_RACE,
   FILTER_FREESTYLE,
   FILTER_CINEMATIC,
   FILTER_NUMBER_MODES
};

uint8_t currentFilterMode = FILTER_FREESTYLE;
filterSpec_s currentFilter = freestyleFilter;

// float minCutoff = 150;  // Hz
// float maxCutoff = 500;  // Hz
// float beta = 0.01f;  // did changing to .02 cause the bumps on the stick bounce?

// slewLimit is now steps per second and gets auto converted when sample rate changes
// NB too high a slew limit will overflow the fixed point math in the filter and cause unstable results
float slewLimit = 150000.0f;  // 10000 limits rate on stick bounce test, 20000 doesn't
// float slewLimit = 0;

// This is actually the rate at which the filters are updated which can be (and is)
// different to the rate the ADCs are running at when using oversampling.
float sampleRate = 8000;    // Hz   XXX keep this in step with the ADC setup

float dCutoff = 50.0f;      // Hz

// OneAUDfilter aud_rollF(minCutoff, maxCutoff, beta, sampleRate, dCutoff, slewLimit);
// OneAUDfilter aud_pitchF(minCutoff, maxCutoff, beta, sampleRate, dCutoff, slewLimit);
// OneAUDfilter aud_yawF(minCutoff, maxCutoff, beta, sampleRate, dCutoff, slewLimit);
// OneAUDfilter aud_throttleF(minCutoff, maxCutoff, beta, sampleRate, dCutoff, slewLimit);

// last param is a guess at the initial value
OneAUDfilterInt aud_roll(currentFilter.minCutoff, currentFilter.maxCutoff, int(1.0f/currentFilter.beta), sampleRate, dCutoff, slewLimit, 2000);
OneAUDfilterInt aud_pitch(currentFilter.minCutoff, currentFilter.maxCutoff, int(1.0f/currentFilter.beta), sampleRate, dCutoff, slewLimit, 2000);
OneAUDfilterInt aud_yaw(currentFilter.minCutoff, currentFilter.maxCutoff, int(1.0f/currentFilter.beta), sampleRate, dCutoff, slewLimit, 2000);
OneAUDfilterInt aud_throttle(currentFilter.minCutoff, currentFilter.maxCutoff, int(1.0f/currentFilter.beta), sampleRate, dCutoff, slewLimit, 300);

// power values in prePA dBm (i.e. what the sx1280 is outputting to the PA or antenna if no PA present)
// int radioPower = -18; // low power testing to check crc/fec behaviour using e28-12
int radioPower = -10; // default for e28-27 (50mW)
// int radioPower = -8; // safe for any module
// int radioPower = -2; // dBm. Max for e28-20
// int radioPower = 0; // dBm. Max for e28-27
// int radioPower = 3; // around 100mW on gnice-27
// int radioPower = 12; // dBm. Testing with e28-12
// gnice-27 max is 13


#define RX_CONNECTION_LOST_TIMEOUT 3000 // Time in ms of no TLM response to consider that we have lost connection

bool isRXconnected = false;

volatile uint8_t NonceTX = 0;

uint32_t SyncPacketLastSent = 0;
uint32_t LastTLMpacketRecvMillis = 0;

SX1280Driver radio;

// telemetry values
int8_t rssi;
uint8_t snr, lq;

#include "crc.h"

GENERIC_CRC8 ota_crc(ELRS_CRC_POLY);



// ======== Interrupt Handlers ============

// Handlers have to be in the C namespace
extern "C" {

// callled at the packet interval to trigger sending rf packets
void TIMER2_IRQHandler(void)
{
   static unsigned long tLast = 0;

   if (SET == timer_interrupt_flag_get(TIMER2, TIMER_INT_CH0))
   {
      unsigned long now = micros();

      // clear interrupt bit or mcu will busy hang
      timer_interrupt_flag_clear(TIMER2, TIMER_INT_CH0);
      interval = tLast == 0 ? 0 : now - tLast;
      tLast = now;

      NonceTX++; // New - just increment the nonce on every frame

      #ifdef ELRS_OG_COMPATIBILITY
      HandleFHSS(); // experimental - can we do fhss here?
      #else
      // fhss is in txdone
      #endif

      SendRCdataToRF();
   }
}

/**
 *    This is where we get notification that there is ADC data ready to be processed
 *    with the 1AUD filter.
 */
unsigned long filterUpdateTime = 0; // for debugging the cpu usage of the filters
void DMA0_Channel0_IRQHandler(void)
{
   static unsigned long last = 0;

   if (SET == dma_interrupt_flag_get(DMA0, DMA_CH0, DMA_INT_FLAG_FTF))
   {
      unsigned long now = micros();
      adcInterval = now - last;
      last = now;

      // clear interrupt bit or mcu will busy hang
      dma_interrupt_flag_clear(DMA0, DMA_CH0, DMA_INT_FLAG_FTF);

      #ifndef ADC_A_CH
      #error "need to define the ADC channel mapping"
      #endif

      aud_roll.update(adc_value[ADC_A_CH]);
      aud_pitch.update(adc_value[ADC_E_CH]);
      aud_throttle.update(adc_value[ADC_T_CH]);
      aud_yaw.update(adc_value[ADC_R_CH]);

      nSamples++;
      now = micros();
      filterUpdateTime += (now - last);
   }   
}

// interrupt handler for rotary encoder push button
void EXTI10_15_IRQHandler(void)
{
   if (RESET != exti_interrupt_flag_get(EXTI_13)){
      exti_interrupt_flag_clear(EXTI_13);
      // if(RESET == gpio_input_bit_get(GPIOA, GPIO_PIN_13)) XXX event loop needs to know about both up and down events
      {
         buttonMoved = true;
         lastButtonTime = millis();
      }
   }
}


void HandleFHSS()
{
   #ifdef ELRS_OG_COMPATIBILITY
   uint8_t modresult = (NonceTX+1) % ExpressLRS_currAirRate_Modparams->FHSShopInterval;
   #else
   uint8_t modresult = (NonceTX + 1) % ExpressLRS_currAirRate_Modparams->FHSShopInterval;
   #endif // ELRS_OG_COMPATIBILITY


   if (modresult == 0) // if it time to hop, do so.
   {
      uint32_t f = FHSSgetNextFreq();
      // printf("f %lu\n\r", f);
      radio.SetFrequency(f);
   }
}

void TXdoneISR()
{
   // printf("TXdone!\n\r");

   // TODO do fhss from timer for both cases
   #ifdef ELRS_OG_COMPATIBILITY
   // fhss moved to timer
   #else
   HandleFHSS();
   #endif

   HandleTLM();
}


// use this for rx and tx done isrs on B8 and B9 (connected to radio DIOs)
void EXTI5_9_IRQHandler(void)
{
   if (exti_interrupt_flag_get(EXTI_8) == SET) {
      exti_interrupt_flag_clear(EXTI_8);
      // printf("RXdone!\n\r");

      // radio.ClearIrqStatus(SX1280_IRQ_RADIO_ALL);

      // gpio_bit_reset(LED_GPIO_PORT, LED_PIN);  // rx has finished, so clear the debug pin

      // TODO move to the event loop?
      radio.readRXData();  // get the data from the sx1280 chip
      ProcessTLMpacket();

   } else if (exti_interrupt_flag_get(EXTI_9) == SET) {
      exti_interrupt_flag_clear(EXTI_9);
      // printf("TXdone!\n\r");

      // radio.ClearIrqStatus(SX1280_IRQ_RADIO_ALL);

      TXdoneISR();
   }
}

// something like this for switches - or maybe just poll them
// void EXTI10_15_IRQHandler(void)
// {

// }

} // extern "C"

// ==================================================

/** extract the gpio port value from a composite port/pin value
 * 
 */
uint32_t PORT(uint32_t compositeGPIOid) {
    uint32_t p = compositeGPIOid >> 16;
    switch (p) {
        case PORTA:
            return GPIOA;
        case PORTB:
            return GPIOB;
        case PORTC:
            return GPIOC;
        default:
            printf("XXX bad port id %lu\n\r", p);
            while(true);
    }

    // can't get here, but suppresses compiler warning
    return 0;
}



/** Sound the beeper
 * NB blocking for duration ms! Will need an async beeper function
 * @param duration time in ms to beep for
 * 
 */
void beep(uint32_t duration)
{
   #ifdef GPIO_BUZZER
   gpio_bit_set(PORT(GPIO_BUZZER), PIN(GPIO_BUZZER));
   delay(duration);
   gpio_bit_reset(PORT(GPIO_BUZZER), PIN(GPIO_BUZZER));
   #endif
}


/** Handle sequences of beeps
 * 
 *  Remember when the current/last beep started,
 *    if now is after beep start + duration, stop the beep
 * 
 *    if now is after beep start + interval, start a new beep
 * 
 * @param interval the delay between beeps in ms
 * @param duration the length of each beep in ms
 * @param currentTime approximate current time in ms
 * 
 * @return true if beeping, false if quiet. Is it useful?
 * 
 * duration should be less than interval. duration of 0 disables beeping
 * 
 * Passes the current time as a param as the call to millis() is quite expensive
 * and we already have a recent value in the caller.
 * 
 */
bool handleBeeps(uint16_t interval, uint16_t duration, uint32_t currentTime)
{
   #ifdef GPIO_BUZZER
   // Static variables to track state across calls
   static uint32_t beepStartTime = 0;
   static bool beeperActive = false;

   if (duration == 0) {
      // make sure the beeper is off
      if (beeperActive) {
         gpio_bit_reset(PORT(GPIO_BUZZER), PIN(GPIO_BUZZER));
         beeperActive = false;
      }
      return false;
   }

   // uint32_t now = millis();

   if (currentTime > (beepStartTime + interval)) {
      if (!beeperActive) {
         // start the beeper
         beepStartTime = currentTime;
         gpio_bit_set(PORT(GPIO_BUZZER), PIN(GPIO_BUZZER));
         beeperActive = true;
      }
      return true;
   }

   if (currentTime > (beepStartTime + duration)) {
      if (beeperActive) {
         // stop the beeper
         gpio_bit_reset(PORT(GPIO_BUZZER), PIN(GPIO_BUZZER));
         beeperActive = false;
      }
      return false;
   }
   #endif // GPIO_BUZZER

   return false;
}


/**
 * Test for our view of if the drone is armed. (armed as in enabled/ready to fly!)
 * Requires that the first switch is the arm switch.
 * Conservatively assume that either middle or high position means armed.
 */
bool isArmed()
{
   return currentSwitches[0] != SWITCH_LOW;
}
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
int main(void)
{
   // uint32_t t0, t1=0;
   // unsigned int nSamples = 0;

   setup();

   Lcd_Init();
   LCD_Clear(DARKBLUE);

   #if defined(T_DISPLAY) || defined(PCB_V1_0)
   setRotation(2);
   #endif

   // startup splash
   BACK_COLOR = DARKBLUE;
   const char * msg = "ExpressLRS";
   int l = strlen(msg);
   int x = LCD_H/2 - l*8/2;
   int y = LCD_W/2 - 8;
   LCD_ShowString(x, y, (u8 const *) msg, WHITE);

   // startup beep?
   #ifdef GPIO_BUZZER
   // beep(30);
   #endif

   delay(500);

   // start the battery monitor ADC (it runs in continuous mode)
   // need to do this before calling checkForChargeMode()
   adc_software_trigger_enable(ADC1, ADC_REGULAR_CHANNEL);

   checkForChargeMode();

   runSafetyChecks();

   LCD_Clear(DARKBLUE);
   BACK_COLOR = DARKBLUE;

   printf("in main\n\r");

   FHSSrandomiseFHSSsequence();

   // Try connecting to the radio
   radio.currFreq = GetInitialFreq();
   radio.Begin();

   #ifdef DISARM_POWER
   radio.SetOutputPower(DISARM_POWER);
   #else
   radio.SetOutputPower(radioPower);
   #endif

   uint8_t linkRateIndex = 0;
   SetRFLinkRate(linkRateIndex);

   // enable the timer for the tx interrupt
   timer_enable(TIMER2);

   // check if we have saved settings in the persistent store
   persistentData_t persistentData = {0,};

   uint8_t res = SimpleStore::read(CONFIG_STORE_ID, sizeof(persistentData), &persistentData);
   if (res == SS_OK) {
      printf("found settings in persistent store\n");

      // unpack the settings from the saved data
      radioPower = persistentData.txPower;
      #ifndef DISARM_POWER
      radio.SetOutputPower(radioPower);
      #endif

      linkRateIndex = persistentData.airmodeIndex;
      SetRFLinkRate(linkRateIndex);

      syncWhenArmed = (bool)persistentData.sync;

      currentFilterMode = persistentData.filterMode;
      updateFilterSettings(currentFilterMode);

      ExpressLRS_currAirRate_Modparams->TLMinterval = (expresslrs_tlm_ratio_e)persistentData.telemRatio;

   } else {
      printf("persistent data not found\n\r");
   }

   // === Next section is the event loop ===

   unsigned long lastDebug = 0;
   int lastEncValue = 100;
   uint8_t lastSWA = SWITCH_LOW;
   uint8_t lastSWB = SWITCH_LOW;
   uint8_t lastSWC = SWITCH_LOW;
   uint8_t lastSWD = SWITCH_LOW;
   unsigned long lastSwitchMoved = 0;
   bool switchesHaveMoved = false;
   uint8_t lastParamToChange = PARAM_NONE;
   bool lcdRedrawNeeded = false;
   uint8_t encRange = 0;
   bool displayNormal = true; // when true, current display is for 'normal' mode, when false, display is for edit mode
   unsigned long uiButtonDown = 0; // timer for long press detection
   bool statusIsArmed = false;
   while(true) 
   {
      // If there is debug info send it to the uart
      // if (debugReady) {
      //    printf("%s\n", debugStr);
      //    debugReady = false;
      // }

      unsigned long now = millis();

      // RC switches

      // get the current status of the switches
      uint32_t newSWA = getSwitchState(SWA_HIGH, SWA_LOW);
      uint32_t newSWB = getSwitchState(SWB_HIGH, SWB_LOW);
      uint32_t newSWC = getSwitchState(SWC_HIGH, SWC_LOW);
      uint32_t newSWD = getSwitchState(SWD_HIGH, SWD_LOW);

      // if any switch has moved, update the timestamp
      if (newSWA != lastSWA || newSWB != lastSWB || newSWC != lastSWC || newSWD != lastSWD) {
         lastSwitchMoved = now;
         lastSWA = newSWA;
         lastSWB = newSWB;
         lastSWC = newSWC;
         lastSWD = newSWD;
         switchesHaveMoved = true; // TODO rename as rcSwitchesHaveMoved to distuinguish from UI stuff?
      }

      // if a switch has moved, but not for more than the debounce time, then update the active state
      if (switchesHaveMoved && ((now - lastSwitchMoved) > 2)) {
         currentSwitches[0] = newSWA;
         currentSwitches[1] = newSWB;
         currentSwitches[2] = newSWC;
         currentSwitches[3] = newSWD;

         printf("switches: %lu %lu %lu %lu\n\r", newSWA, newSWB, newSWC, newSWD);

         // clear the flag so we don't spam this code
         switchesHaveMoved = false;

         // cancel edit mode if switches are being moved
         if (paramToChange != PARAM_NONE) {
            lastParamToChange = paramToChange;
            paramToChange = PARAM_NONE;
         }

         // since a switch change might cause a display change, force a quick update
         lcdRedrawNeeded = true;
      }

      // Timeout edit mode if UI hasn't been touched
      // Don't worry about wrap around, it's not worth the effort
      if ((paramToChange != PARAM_NONE) && (now  > (lastButtonTime + 15000))) {
         lastParamToChange = paramToChange;
         paramToChange = PARAM_NONE;
         lcdRedrawNeeded = true;
      }

      // Check for long press on the ui button
      // Don't worry about wrap around
      if (uiButtonDown && (now > (uiButtonDown + 1000))) {
         // long press
         printf("long press detected\n\r");
         uiButtonDown = 0; // clear the timer so we don't spam through this code

         LCD_Clear(DARKBLUE);

         BACK_COLOR = YELLOW;
         const char * msg = "SAVED";
         int l = strlen(msg);
         int x = LCD_H/2 - l*8/2;
         int y = LCD_W/2 - 8;
         LCD_ShowString(x, y, (u8 const *) msg, BLACK);

         // populate the data structure
         persistentData.txPower = radioPower;
         persistentData.airmodeIndex = ExpressLRS_currAirRate_Modparams->index;
         persistentData.sync = syncWhenArmed;
         persistentData.filterMode = currentFilterMode;
         persistentData.telemRatio = ExpressLRS_currAirRate_Modparams->TLMinterval;

         SimpleStore::write(CONFIG_STORE_ID, sizeof(persistentData), &persistentData);

         // give the user time to bask in his success
         delay(500);

         LCD_Clear(DARKBLUE);         
         BACK_COLOR = DARKBLUE;
      }

      // UI button (press down on the rotary enc)
      // TODO add double click, use to exit the settings screen (or maybe change between screens, or action a menu item?)
      if (buttonMoved && ((now - lastButtonTime) > 5)) { // time for the button to stop bouncing
         // check the current button state, pressed is pin low
         if(RESET == gpio_input_bit_get(RE_BUTTON_PORT, RE_BUTTON_PIN))
         {
            // printf("ui button pressed\n\r");

            // save the button down time for long press detection
            uiButtonDown = now;

            if (paramToChange == PARAM_NONE && lastParamToChange != PARAM_NONE) {
               paramToChange = lastParamToChange;
               lastParamToChange = PARAM_NONE; // to make sure we only use this once after a timeout
            } else {
               paramToChange = (paramToChange + 1) % PARAM_N_PARAMS;
               // skip PARAM_NONE as that causes exit from edit mode
               if (paramToChange == PARAM_NONE) paramToChange++;
            }
            lcdRedrawNeeded = true; // update the screen immediately 

            // setup the rotary encoder for the selected param
            // The encoder count changes by 2 for each click, so ranges have a *2 multiplier
            switch (paramToChange) {
               case PARAM_POWER:
                  encRange = ((MAX_PRE_PA_POWER + 18) * 2); // MAX_PRE_PA_POWER is the last usable value, not the number of values, so don't subtract 1
                  lastEncValue = (radioPower + 18) * 2 + 100;
                  // printf("currP %d lastEnc %u\n\r", radio.currPWR, lastEncValue);
                  break;

               case PARAM_RATE:
                  encRange = (RATE_MAX - 1) * 2;
                  lastEncValue = ExpressLRS_currAirRate_Modparams->index * 2 + 100;
                  break;

               case PARAM_TLM_INT:
                  encRange = (TLM_RATIO_NUM_VALUES - 1) * 2;
                  lastEncValue = ExpressLRS_currAirRate_Modparams->TLMinterval * 2 + 100;
                  break;

               case PARAM_FILTER_MODE:
                  encRange = (FILTER_NUMBER_MODES - 1) * 2;
                  lastEncValue = currentFilterMode * 2 + 100;
                  break;

               case PARAM_SYNC_WHEN_ARMED:
                  encRange = 2;
                  lastEncValue = syncWhenArmed ? 102 : 100;
            }

            // printf("setting lastEncValue %u\n\r", lastEncValue);
            timer_counter_value_config(TIMER3, lastEncValue);

         } else {
            uiButtonDown = 0; // cancel long button detection if the button is now up
         }
         buttonMoved = false;
      }

      int encValue = timer_counter_read(TIMER3);
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

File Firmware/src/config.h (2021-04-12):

#pragma once

// which board are we using

// #define LONGAN_NANO
// #define T_DISPLAY
#define PCB_V1_0

// some things are specific to each build

// #define PROTOTYPE_V3
// #define PROTOTYPE_V4
#define PROTOTYPE_V5

// testing compat mode with mainstream elrs rx
// TODO make dynamic
#define ELRS_OG_COMPATIBILITY

#ifdef ELRS_OG_COMPATIBILITY
    #define Regulatory_Domain_ISM_2400
#else
    #define Regulatory_Domain_ISM_2400_NA
#endif

// TODO make this runtime dynamic
// define the type of radio module being used 

// #define RADIO_E28_12    // CAREFUL - this will break _20 and _27 if you use it by accident
// #define RADIO_E28_20
#define RADIO_E28_27

#ifdef RADIO_E28_12
// E28-12 and both GNICERF modules can use the full output range
#define MAX_PRE_PA_POWER 13
#define DISARM_POWER (0)
#elif defined(RADIO_E28_20)
#define MAX_PRE_PA_POWER (-2)
#define DISARM_POWER (-12)
#elif defined(RADIO_E28_27)
#define MAX_PRE_PA_POWER 0
#define DISARM_POWER (-15)
#endif



// how many switches do we have?
// hybrid 8 currently deals with up to 8 switches, but if we only have 4 fitted we can save some time by
// setting the lower value here
#define MAX_SWITCHES    4


// definitions for simpler gpio naming scheme

enum ports {
    PORTA,
    PORTB,
    PORTC
};

#define PA1  (PORTA << 16 | GPIO_PIN_1)
#define PA2  (PORTA << 16 | GPIO_PIN_2)
#define PA3  (PORTA << 16 | GPIO_PIN_3)
#define PA4  (PORTA << 16 | GPIO_PIN_4)
#define PA5  (PORTA << 16 | GPIO_PIN_5)
#define PA6  (PORTA << 16 | GPIO_PIN_6)
#define PA7  (PORTA << 16 | GPIO_PIN_7)
#define PA8  (PORTA << 16 | GPIO_PIN_8)
#define PA9  (PORTA << 16 | GPIO_PIN_9)
#define PA10 (PORTA << 16 | GPIO_PIN_10)
#define PA11 (PORTA << 16 | GPIO_PIN_11)
#define PA12 (PORTA << 16 | GPIO_PIN_12)
#define PA13 (PORTA << 16 | GPIO_PIN_13)
#define PA14 (PORTA << 16 | GPIO_PIN_14)
#define PA15 (PORTA << 16 | GPIO_PIN_15)

#define PB1  (PORTB << 16 | GPIO_PIN_1)
#define PB2  (PORTB << 16 | GPIO_PIN_2)
#define PB3  (PORTB << 16 | GPIO_PIN_3)
#define PB4  (PORTB << 16 | GPIO_PIN_4)
#define PB5  (PORTB << 16 | GPIO_PIN_5)
#define PB6  (PORTB << 16 | GPIO_PIN_6)
#define PB7  (PORTB << 16 | GPIO_PIN_7)
#define PB8  (PORTB << 16 | GPIO_PIN_8)
#define PB9  (PORTB << 16 | GPIO_PIN_9)
#define PB10 (PORTB << 16 | GPIO_PIN_10)
#define PB11 (PORTB << 16 | GPIO_PIN_11)
#define PB12 (PORTB << 16 | GPIO_PIN_12)
#define PB13 (PORTB << 16 | GPIO_PIN_13)
#define PB14 (PORTB << 16 | GPIO_PIN_14)
#define PB15 (PORTB << 16 | GPIO_PIN_15)

#define PC1  ((PORTC << 16) | GPIO_PIN_1)
#define PC2  ((PORTC << 16) | GPIO_PIN_2)
#define PC3  ((PORTC << 16) | GPIO_PIN_3)
#define PC4  ((PORTC << 16) | GPIO_PIN_4)
#define PC5  ((PORTC << 16) | GPIO_PIN_5)
#define PC6  ((PORTC << 16) | GPIO_PIN_6)
#define PC7  ((PORTC << 16) | GPIO_PIN_7)
#define PC8  ((PORTC << 16) | GPIO_PIN_8)
#define PC9  ((PORTC << 16) | GPIO_PIN_9)
#define PC10 ((PORTC << 16) | GPIO_PIN_10)
#define PC11 ((PORTC << 16) | GPIO_PIN_11)
#define PC12 ((PORTC << 16) | GPIO_PIN_12)
#define PC13 ((PORTC << 16) | GPIO_PIN_13)
#define PC14 ((PORTC << 16) | GPIO_PIN_14)
#define PC15 ((PORTC << 16) | GPIO_PIN_15)


#define PIN(x) (x & 0xFFFF)

// =====================




#ifdef LONGAN_NANO

// #define RADIO_BUSY_PORT GPIOA
// #define RADIO_BUSY_PIN  GPIO_PIN_11

// #define RADIO_RESET_PORT GPIOA
// #define RADIO_RESET_PIN GPIO_PIN_12

#define RADIO_BUSY_PORT GPIOA
#define RADIO_BUSY_PIN  GPIO_PIN_12

#define RADIO_RESET_PORT GPIOA
#define RADIO_RESET_PIN GPIO_PIN_11


// rotary encoder button
// #define RE_BUTTON_PORT GPIOA
// #define RE_BUTTON_PIN GPIO_PIN_4

#define RE_BUTTON_PORT GPIOC
#define RE_BUTTON_PIN GPIO_PIN_13

// for testing on the nano
// #define SWB_TMP PA14

#define SWA_LOW  PC15
#define SWA_HIGH PC14

#define SWB_LOW  PA13
#define SWB_HIGH PA14

#define SWC_LOW PA15
#define SWC_HIGH PB3

#define SWD_LOW  PB5
#define SWD_HIGH PB4

// need adc scaling constants even if we don't have anything connected
#define ADC_PITCH_REVERSED false
#define ADC_PITCH_MIN 726u
#define ADC_PITCH_CTR 2080u
#define ADC_PITCH_MAX 3497u

#define ADC_ROLL_REVERSED true
#define ADC_ROLL_MIN 592u
#define ADC_ROLL_CTR 2083u
#define ADC_ROLL_MAX 3547u

#define ADC_THROTTLE_REVERSED true
#define ADC_THROTTLE_MIN 561u
#define ADC_THROTTLE_MAX 3504u

#define ADC_YAW_REVERSED false
#define ADC_YAW_MIN 741u
#define ADC_YAW_CTR 2081u
#define ADC_YAW_MAX 3436u


#elif defined(T_DISPLAY)

#define RADIO_BUSY_PORT GPIOA
#define RADIO_BUSY_PIN  GPIO_PIN_12

#define RADIO_RESET_PORT GPIOA
#define RADIO_RESET_PIN GPIO_PIN_11

#define RADIO_RXEN_PORT GPIOB
#define RADIO_RXEN_PIN GPIO_PIN_11

#define RADIO_TXEN_PORT GPIOA
#define RADIO_TXEN_PIN GPIO_PIN_8

// rotary encoder button
#define RE_BUTTON_PORT GPIOC
#define RE_BUTTON_PIN GPIO_PIN_13

// RC switches
#define SWA_LOW  PC15
#define SWA_HIGH PC14

// #define SWB_TMP PA13
#define SWB_LOW  PA13
#define SWB_HIGH PA14

#define SWC_LOW PA15
#define SWC_HIGH PB3

#define SWD_LOW  PB5
#define SWD_HIGH PB4
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
